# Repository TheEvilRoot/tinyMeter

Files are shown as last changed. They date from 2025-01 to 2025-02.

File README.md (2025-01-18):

# tinyMeter

Current/voltage meter board for 5V and 12V rails.

Provides:
- two USB-A outputs at 5V from single USB-C input 5V@3A max.
- one DC Jack output from DC jack output, 30V max.

Board is powered from separate USB-C with data lines connected MCU.

3V3 rail is powered by AMS1117-3.3 LDO regulator from master USB-C VBUS.

Has ESP32-S3 SoC as a MCU with in-package PSRAM and Flash. WiFi/Bluetooth antenna is implemented on PCB.

Power meter capability is done using INA219 chips from TI and 25mOhm shunts on power rails. Each rails can also be turned on/off by MCU using 100N03A N-channel MOSFETs on each rail.

Board supports ST7789 display connection using 0.7mm pitch FPC connector. 

Cuurrent PCB looks like:
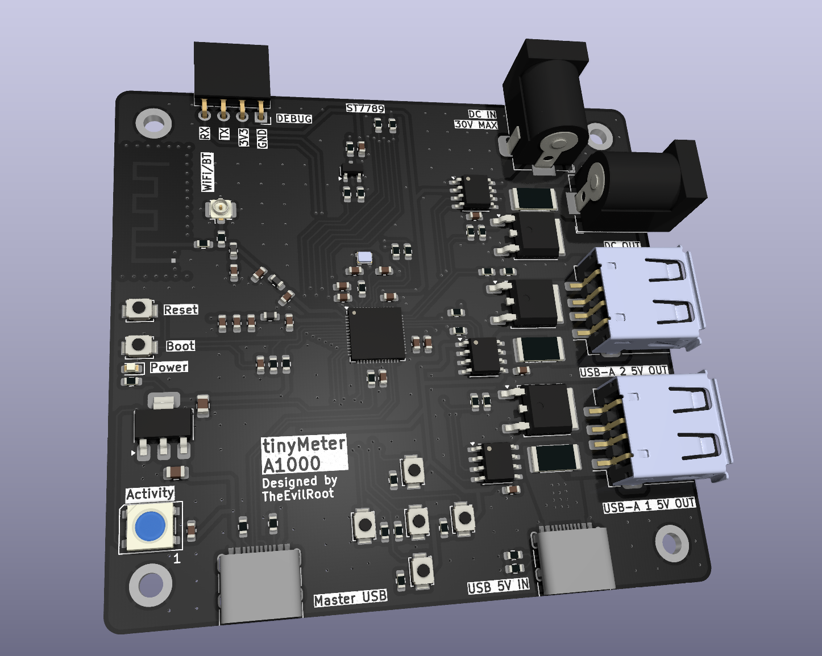
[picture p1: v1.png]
PCB


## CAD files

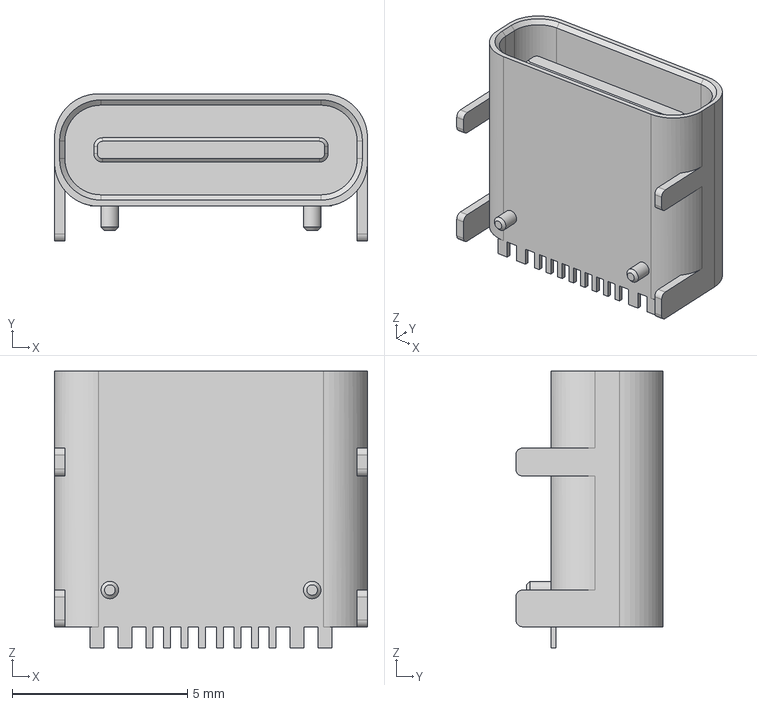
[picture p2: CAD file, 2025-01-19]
HRO TYPE-C-31-M-12.step
8.94 x 4.21 x 7.90 mm

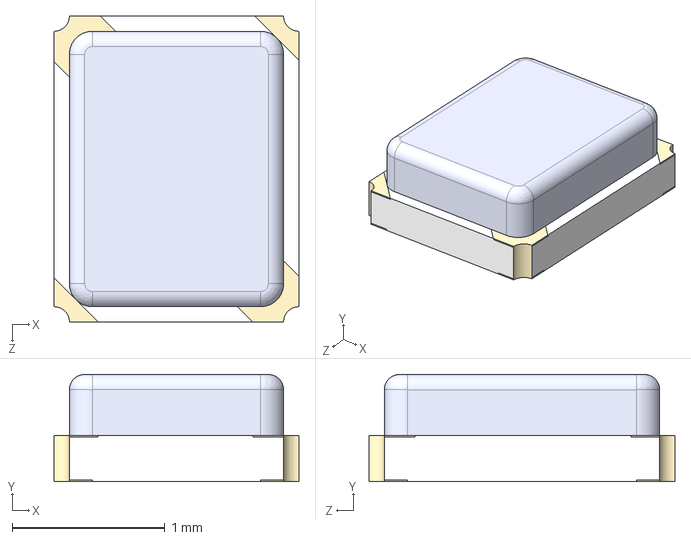
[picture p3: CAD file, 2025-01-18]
XRCGB40M000F4M00R0.step
1.60 x 0.7 x 2.00 mm

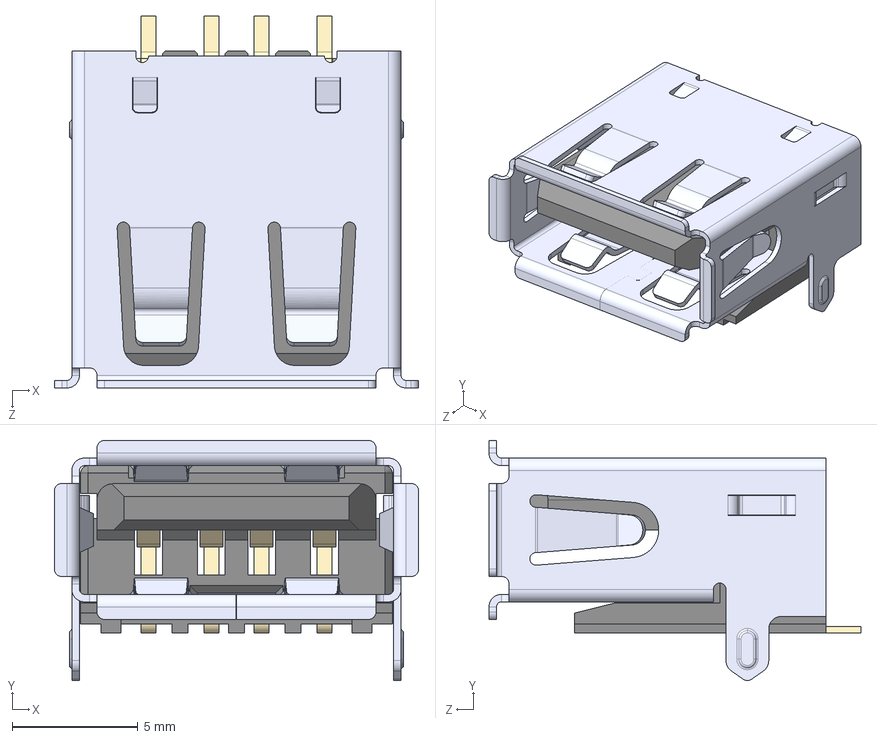
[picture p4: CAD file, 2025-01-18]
USB1046-XX-XXXX-X-B-X_REVB.step
14.5 x 9.55 x 14.8 mm

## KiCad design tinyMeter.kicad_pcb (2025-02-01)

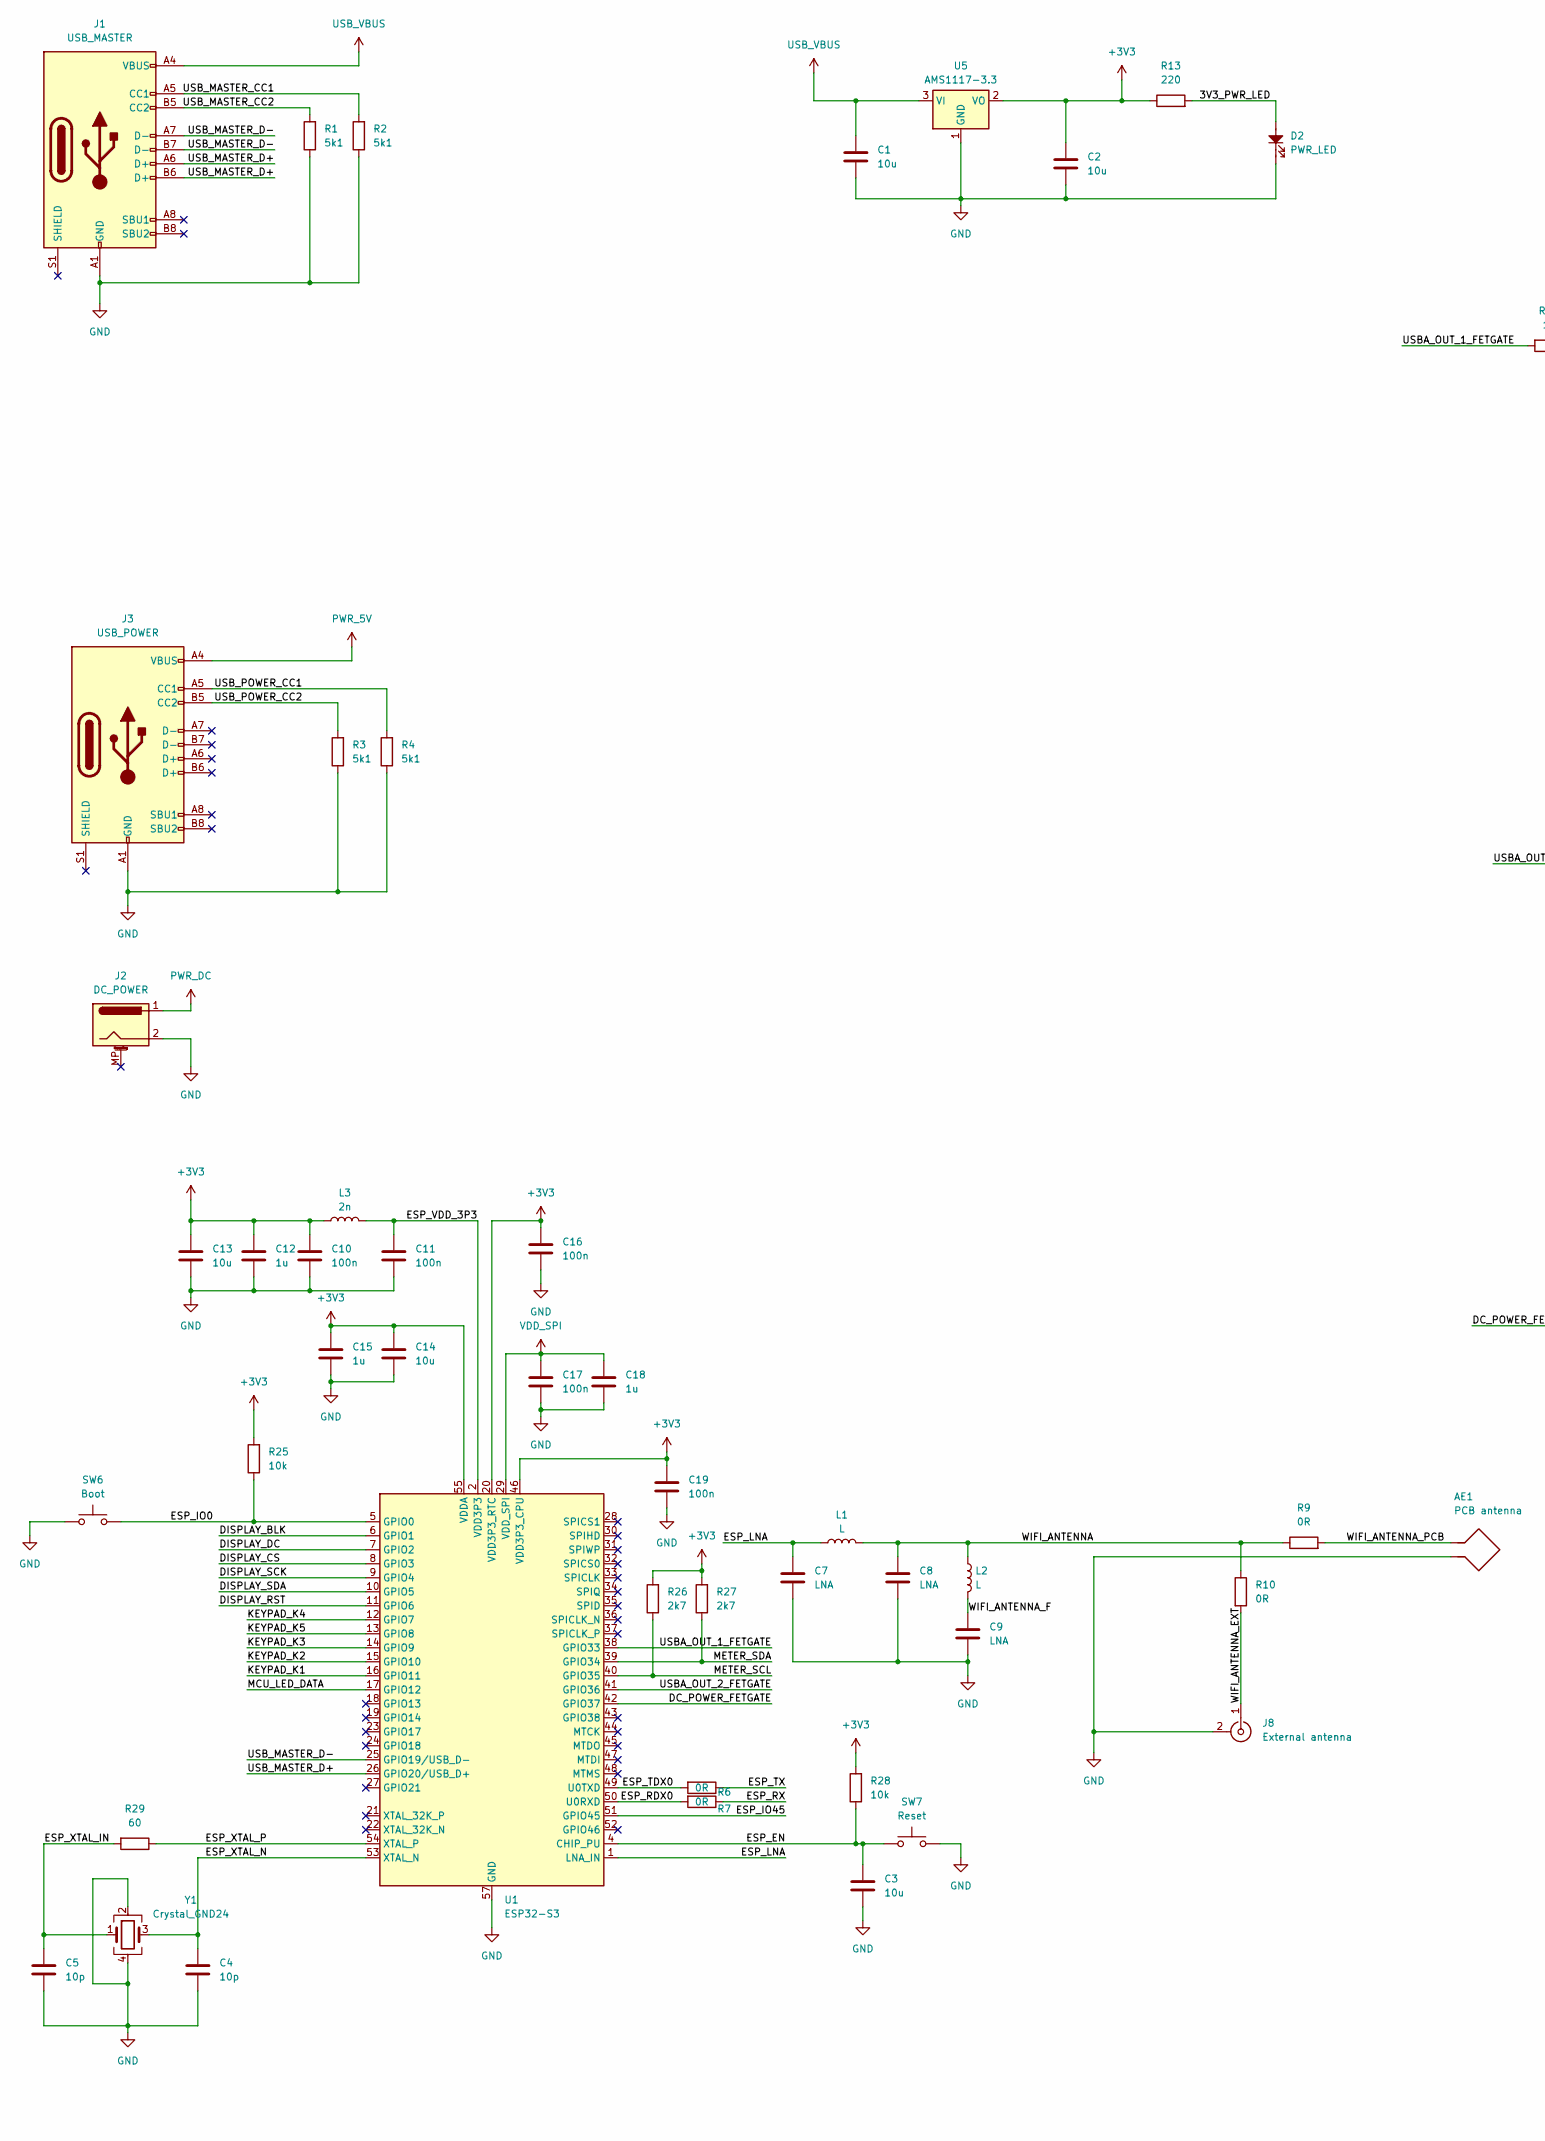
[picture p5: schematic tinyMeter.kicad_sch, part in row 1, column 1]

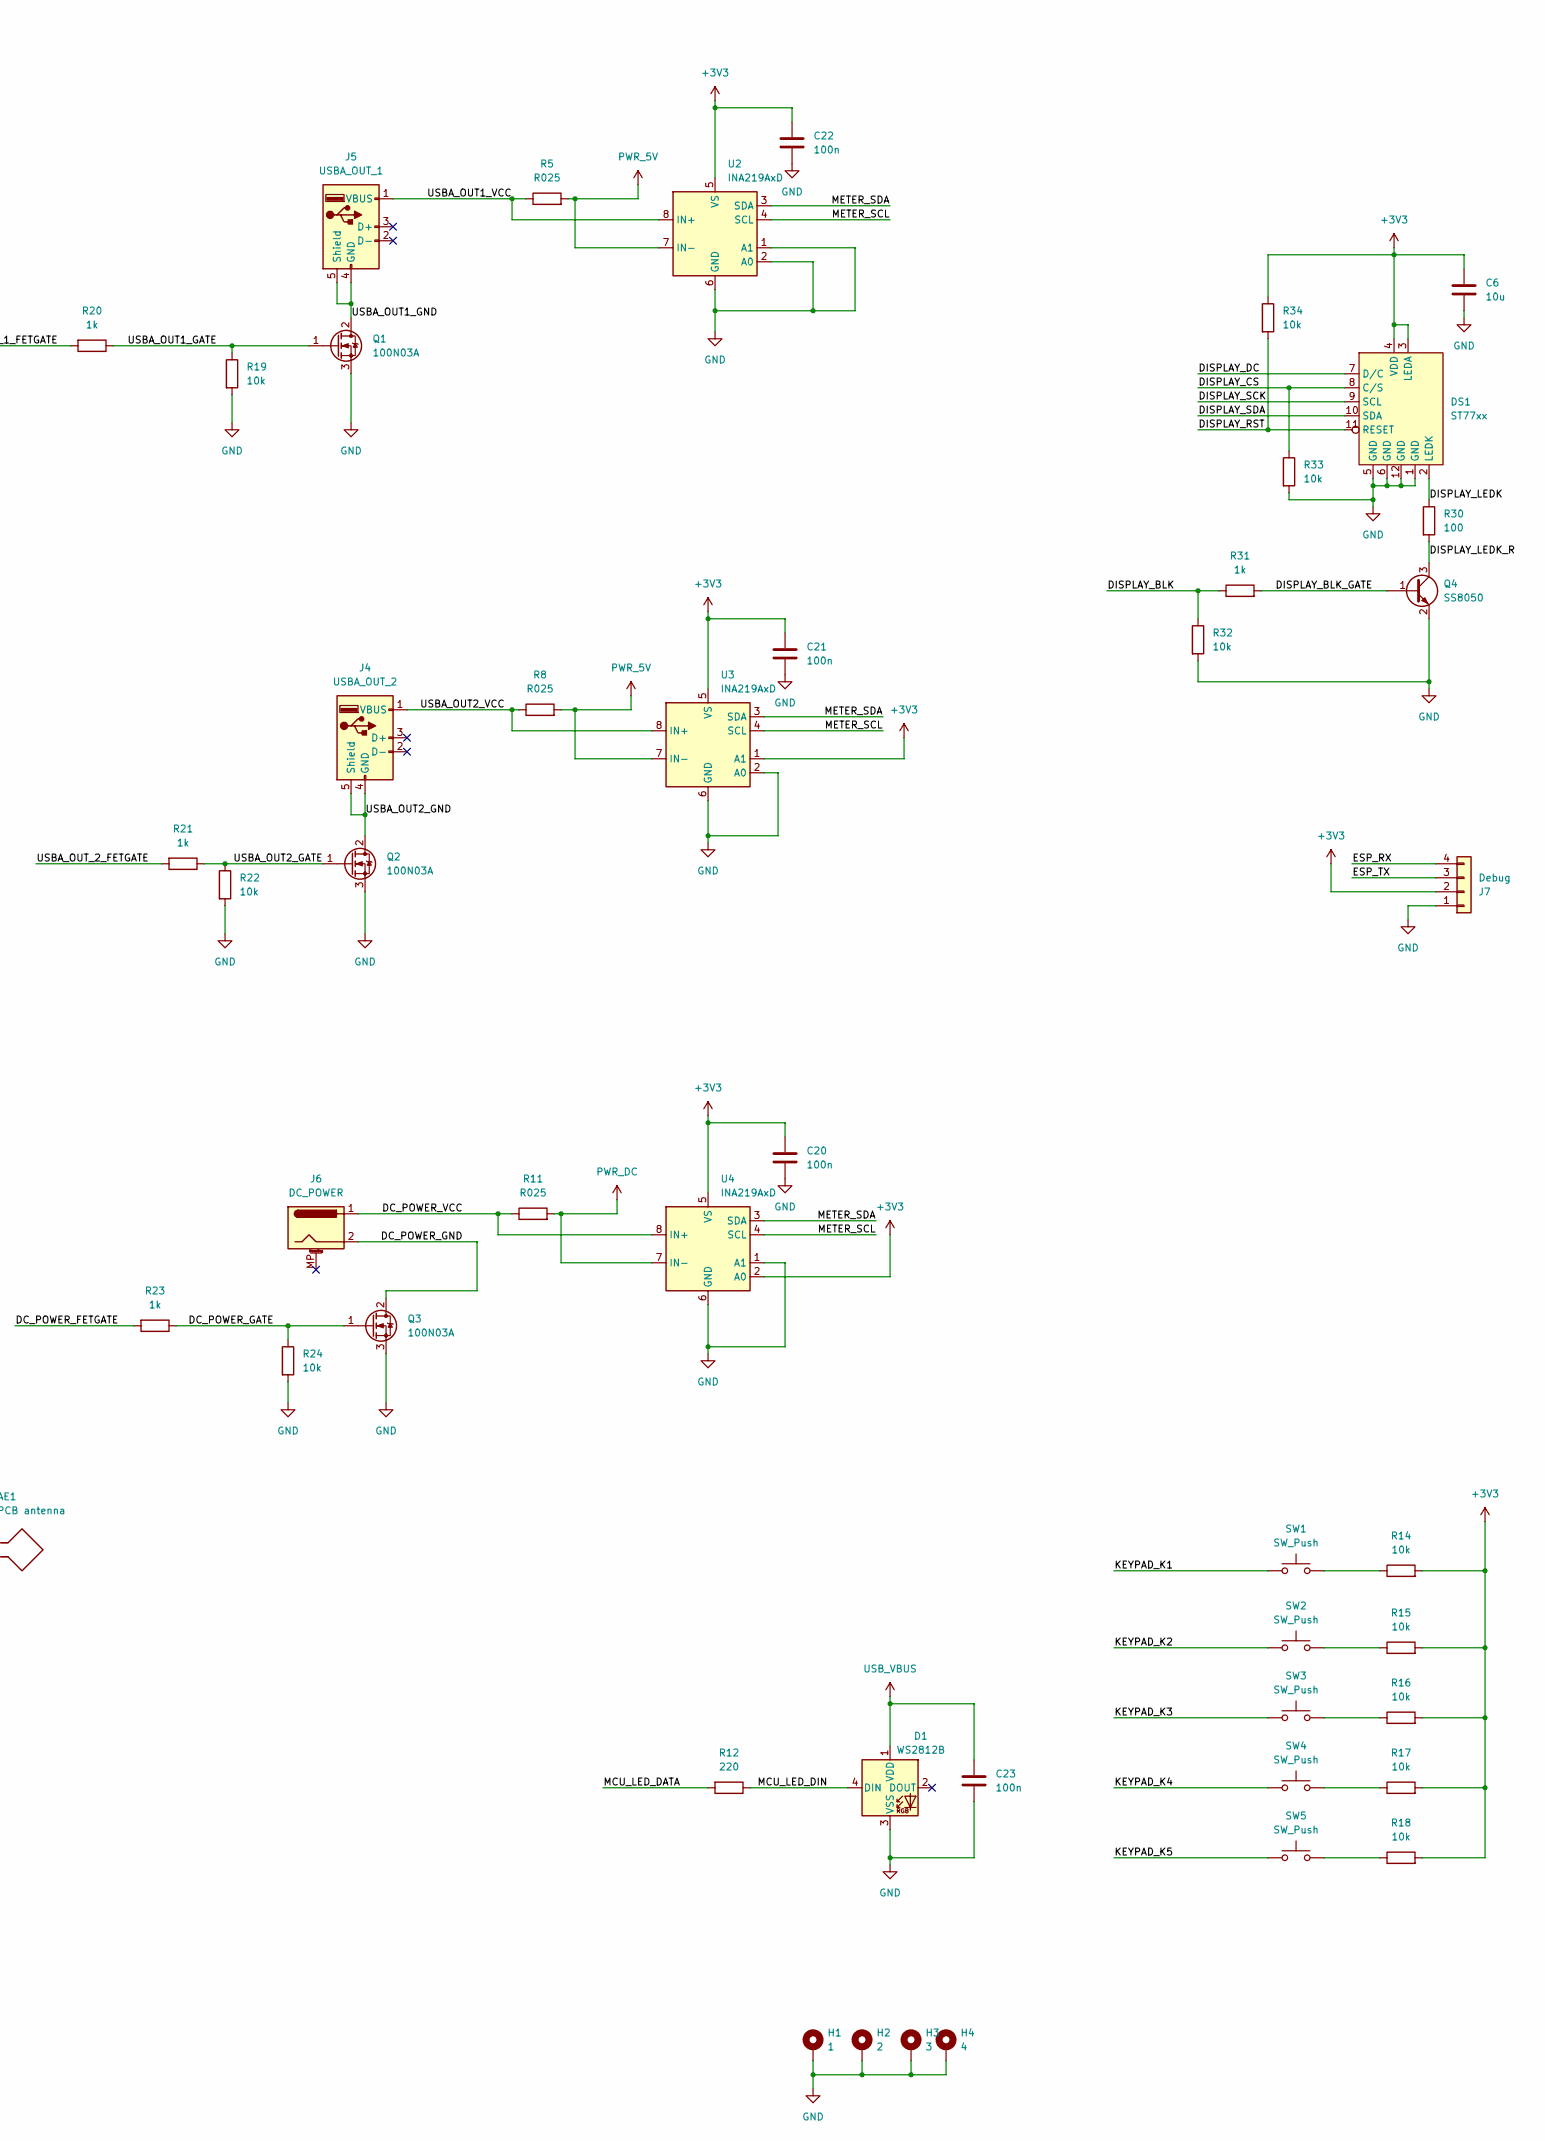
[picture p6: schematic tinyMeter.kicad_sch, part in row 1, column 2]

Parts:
AE1: PCB antenna; ESPRESSIF_ESP32_MIFA_2.4GHz_Right
C1, C2: 10u; C_0805_2012Metric
C3, C6, C13, C14: 10u; C_0603_1608Metric
C4, C5: 10p; C_0603_1608Metric
C7, C8, C9: LNA; C_0603_1608Metric
C10, C11, C16, C17, C19, C20, C21, C22, C23: 100n; C_0603_1608Metric
C12, C15, C18: 1u; C_0603_1608Metric
D1: WS2812B; LED_WS2812B_PLCC4_5.0x5.0mm_P3.2mm
D2: PWR_LED; LED_0603_1608Metric
DS1: ST77xx; ST77XX
H1: 1; MountingHole_2.7mm_M2.5_DIN965_Pad
H2: 2; MountingHole_2.7mm_M2.5_DIN965_Pad
H3: 3; MountingHole_2.7mm_M2.5_DIN965_Pad
H4: 4; MountingHole_2.7mm_M2.5_DIN965_Pad
J1: USB_MASTER; USB_C_Receptacle_HRO_TYPE-C-31-M-12
J2, J6: DC_POWER; BarrelJack_Horizontal
J3: USB_POWER; USB_C_Receptacle_HRO_TYPE-C-31-M-12
J4: USBA_OUT_2; USB_A_Receptacle_GCT_USB1046
J5: USBA_OUT_1; USB_A_Receptacle_GCT_USB1046
J7: Debug; PinSocket_1x04_P2.54mm_Horizontal
J8: External antenna; U.FL_Hirose_U.FL-R-SMT-1_Vertical
L1, L2: L; L_0603_1608Metric
L3: 2n; L_0603_1608Metric
Q1, Q2, Q3: 100N03A; TO-252-2
Q4: SS8050; SOT-23
R1, R2, R3, R4: 5k1; R_0603_1608Metric
R5, R8, R11: R025; R_2512_6332Metric
R6, R7, R9, R10: 0R; R_0603_1608Metric
R12, R13: 220; R_0603_1608Metric
R14, R15, R16, R17, R18, R19, R22, R24, R25, R28, R32, R33, R34: 10k; R_0603_1608Metric
R20, R21, R23, R31: 1k; R_0603_1608Metric
R26, R27: 2k7; R_0603_1608Metric
R29: 60; R_0603_1608Metric
R30: 100; R_0603_1608Metric
SW1, SW2, SW3, SW4, SW5: SW_Push; SW_SPST_B3U-1000P
SW6: Boot; SW_SPST_B3U-1000P
SW7: Reset; SW_SPST_B3U-1000P
U1: ESP32-S3; QFN-56-1EP_7x7mm_P0.4mm_EP4x4mm
U2, U3, U4: INA219AxD; SOIC-8_3.9x4.9mm_P1.27mm
U5: AMS1117-3.3; SOT-223-3_TabPin2
Y1: Crystal_GND24; OSC_XRCGB40M000F4M00R0

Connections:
+3V3: C2.1, C6.1, C10.1, C12.1, C13.1, C14.1, C15.1, C16.1, C19.1, C20.1, C21.1, C22.1, DS1.3 (LEDA), DS1.4 (VDD), J7.2, L3.1, R13.1, R14.2, R15.2, R16.2, R17.2, R18.2, R25.2, R26.2, R27.2, R28.2, R34.1, U1.20 (VDD3P3_RTC), U1.46 (VDD3P3_CPU), U1.55 (VDDA), U1.56 (VDDA), U2.5 (VS), U3.1 (A1), U3.5 (VS), U4.2 (A0), U4.5 (VS), U5.2 (VO)
/3V3_PWR_LED: D2.2, R13.2
/DC_POWER_FETGATE: R23.2, U1.42 (GPIO37)
/DC_POWER_GATE: Q3.1 (G), R23.1, R24.1
/DC_POWER_GND: J6.2, Q3.2 (D)
/DC_POWER_VCC: J6.1, R11.1, U4.8 (IN+)
/DISPLAY_BLK: R31.1, R32.1, U1.6 (GPIO1)
/DISPLAY_BLK_GATE: Q4.1 (B), R31.2
/DISPLAY_CS: DS1.8 (C/S), R33.1, U1.8 (GPIO3)
/DISPLAY_DC: DS1.7 (D/C), U1.7 (GPIO2)
/DISPLAY_LEDK: DS1.2 (LEDK), R30.1
/DISPLAY_LEDK_R: Q4.3 (C), R30.2
/DISPLAY_RST: DS1.11 (RESET), R34.2, U1.11 (GPIO6)
/DISPLAY_SCK: DS1.9 (SCL), U1.9 (GPIO4)
/DISPLAY_SDA: DS1.10 (SDA), U1.10 (GPIO5)
/ESP_EN: C3.1, R28.1, SW7.1, U1.4 (CHIP_PU)
/ESP_IO0: R25.1, SW6.2, U1.5 (GPIO0)
/ESP_IO45: U1.51 (GPIO45)
/ESP_LNA: C7.1, L1.1, U1.1 (LNA_IN)
/ESP_RDX0: R7.2, U1.50 (U0RXD)
/ESP_RX: J7.4, R7.1
/ESP_TDX0: R6.2, U1.49 (U0TXD)
/ESP_TX: J7.3, R6.1
/ESP_VDD_3P3: C11.1, L3.2, U1.2 (VDD3P3), U1.3 (VDD3P3)
/ESP_XTAL_IN: C5.1, R29.2, Y1.1
/ESP_XTAL_N: C4.1, U1.53 (XTAL_N), Y1.3
/ESP_XTAL_P: R29.1, U1.54 (XTAL_P)
/KEYPAD_K1: SW1.1, U1.16 (GPIO11)
/KEYPAD_K2: SW2.1, U1.15 (GPIO10)
/KEYPAD_K3: SW3.1, U1.14 (GPIO9)
/KEYPAD_K4: SW4.1, U1.12 (GPIO7)
/KEYPAD_K5: SW5.1, U1.13 (GPIO8)
/MCU_LED_DATA: R12.2, U1.17 (GPIO12)
/MCU_LED_DIN: D1.4 (DIN), R12.1
/METER_SCL: R26.1, U1.40 (GPIO35), U2.4 (SCL), U3.4 (SCL), U4.4 (SCL)
/METER_SDA: R27.1, U1.39 (GPIO34), U2.3 (SDA), U3.3 (SDA), U4.3 (SDA)
/USBA_OUT1_GATE: Q1.1 (G), R19.1, R20.1
/USBA_OUT1_GND: J5.4 (GND), J5.5 (Shield), Q1.2 (D)
/USBA_OUT1_VCC: J5.1 (VBUS), R5.1, U2.8 (IN+)
/USBA_OUT2_GATE: Q2.1 (G), R21.1, R22.1
/USBA_OUT2_GND: J4.4 (GND), J4.5 (Shield), Q2.2 (D)
/USBA_OUT2_VCC: J4.1 (VBUS), R8.1, U3.8 (IN+)
/USBA_OUT_1_FETGATE: R20.2, U1.38 (GPIO33)
/USBA_OUT_2_FETGATE: R21.2, U1.41 (GPIO36)
/USB_MASTER_CC1: J1.A5 (CC1), R2.2
/USB_MASTER_CC2: J1.B5 (CC2), R1.2
/USB_MASTER_D+: J1.A6 (D+), J1.B6 (D+), U1.26 (GPIO20/USB_D+)
/USB_MASTER_D-: J1.A7 (D-), J1.B7 (D-), U1.25 (GPIO19/USB_D-)
/USB_POWER_CC1: J3.A5 (CC1), R4.2
/USB_POWER_CC2: J3.B5 (CC2), R3.2
/WIFI_ANTENNA: C8.1, L1.2, L2.1, R9.1, R10.1
/WIFI_ANTENNA_EXT: J8.1 (In), R10.2
/WIFI_ANTENNA_F: C9.1, L2.2
/WIFI_ANTENNA_PCB: AE1.1, R9.2
GND: AE1.2, C1.2, C2.2, C3.2, C4.2, C5.2, C6.2, C7.2, C8.2, C9.2, C10.2, C11.2, C12.2, C13.2, C14.2, C15.2, C16.2, C17.2, C18.2, C19.2, C20.2, C21.2, C22.2, C23.2, D1.3 (VSS), D2.1, DS1.1 (GND), DS1.5 (GND), DS1.6 (GND), DS1.12 (GND), H1.1, H2.1, H3.1, H4.1, J1.A1 (GND), J1.A12 (GND), J1.B1 (GND), J1.B12 (GND), J2.2, J3.A1 (GND), J3.A12 (GND), J3.B1 (GND), J3.B12 (GND), J7.1, J8.2 (Ext), Q1.3 (S), Q2.3 (S), Q3.3 (S), Q4.2 (E), R1.1, R2.1, R3.1, R4.1, R19.2, R22.2, R24.2, R32.2, R33.2, SW6.1, SW7.2, U1.57 (GND), U2.1 (A1), U2.2 (A0), U2.6 (GND), U3.2 (A0), U3.6 (GND), U4.1 (A1), U4.6 (GND), U5.1 (GND), Y1.2, Y1.4
unnamed: R14.1, SW1.2
unnamed: R15.1, SW2.2
unnamed: R16.1, SW3.2
unnamed: R17.1, SW4.2
unnamed: R18.1, SW5.2
PWR_5V: J3.A4 (VBUS), J3.A9 (VBUS), J3.B4 (VBUS), J3.B9 (VBUS), R5.2, R8.2, U2.7 (IN-), U3.7 (IN-)
PWR_DC: J2.1, R11.2, U4.7 (IN-)
USB_VBUS: C1.1, C23.1, D1.1 (VDD), J1.A4 (VBUS), J1.A9 (VBUS), J1.B4 (VBUS), J1.B9 (VBUS), U5.3 (VI)
VDD_SPI: C17.1, C18.1, U1.29 (VDD_SPI)

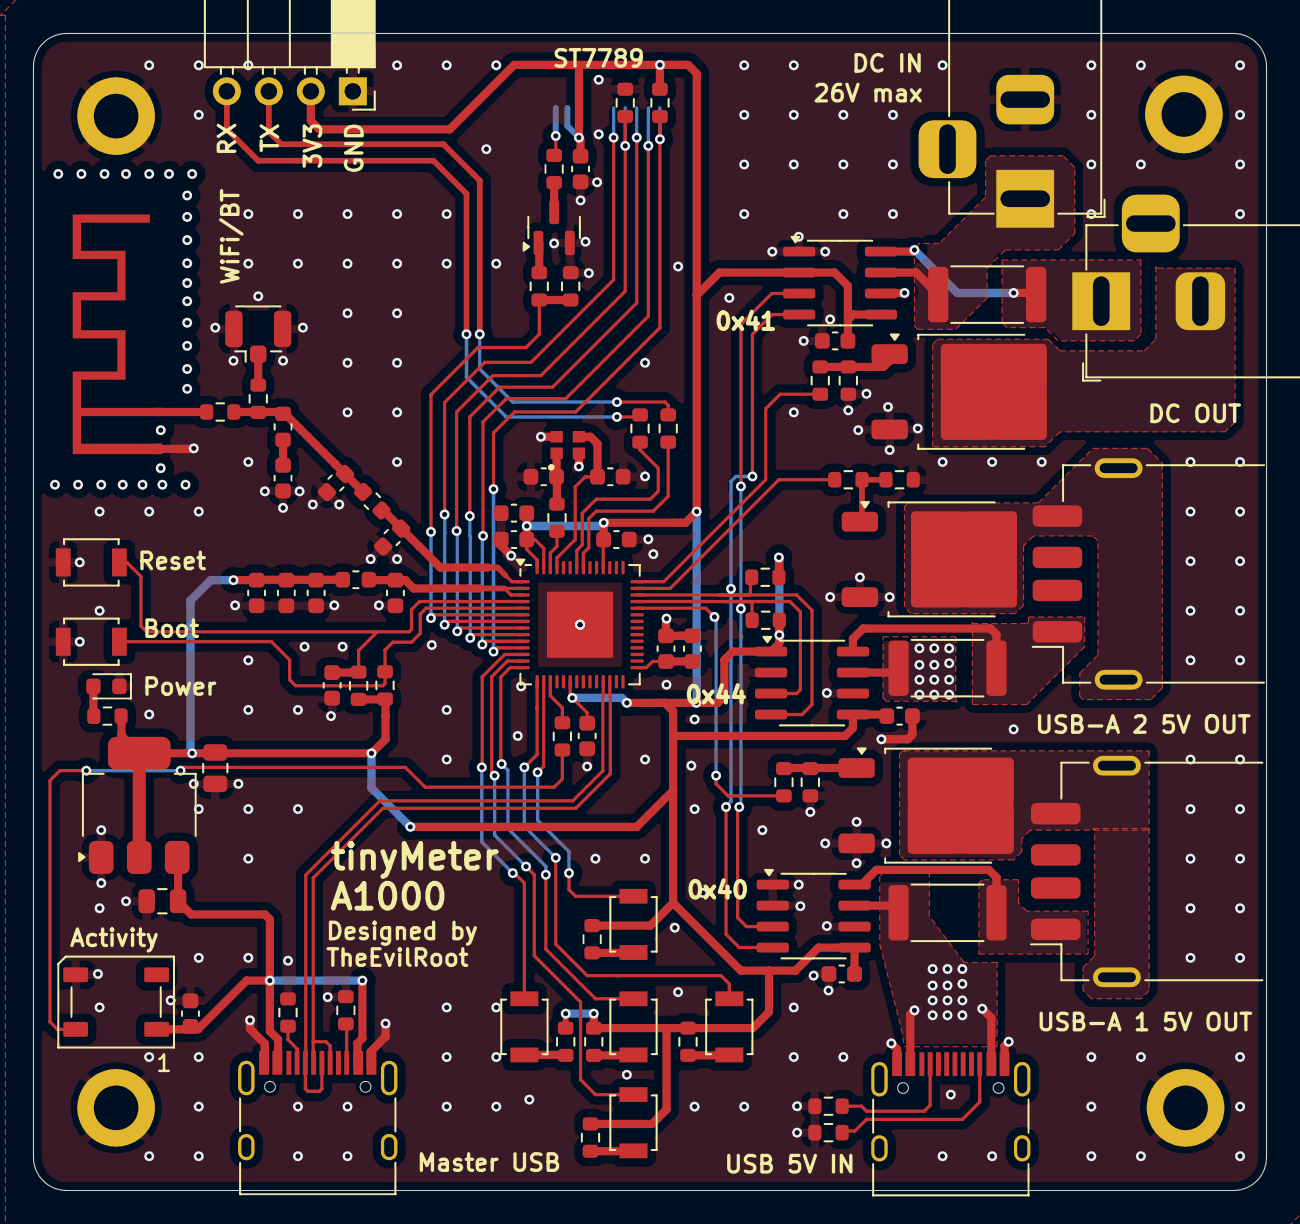
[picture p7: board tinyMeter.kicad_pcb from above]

Board: 2 copper layers, 74.6 x 70.0 mm, 93 parts (1 on the bottom side), 63 nets.

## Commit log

2025-01-17 v1 start
    [tinyMeter.kicad_pcb, tinyMeter.kicad_sch]
2025-01-17 Rough schematic and start of layout
    [tinyMeter.kicad_pcb, tinyMeter.kicad_sch]
2025-01-18 Rough layout and routing
    [USB1046-XX-XXXX-X-B-X_REVB.step, tinyMeter.kicad_pcb, tinyMeter.kicad_sch]
2025-01-18 More layout
    - Some traces refactor
    - Add debug connector with UART lines
    - Add external WiFi/BT connector and selector for PCB/Ext
    - Add WS8212B LED just for fun
    - Add power indication LED on 3V3
    - Remove RefDes silkscreen; add useful silkscreen
    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
    [XRCGB40M000F4M00R0.step, tinyMeter.kicad_pcb, tinyMeter.kicad_sch]
2025-01-19 Fixes and schematic refactor
    - Refactor schematic to get more space
    - Assign nets where missing
    - Change footprint of USB-C
    - Add 3D model for USB-C footprint
    - Changes to board setup
    [HRO TYPE-C-31-M-12.step, tinyMeter.kicad_pcb, tinyMeter.kicad_sch]
2025-01-19 Some rerouting. Via stitching. Align mouting holes
    [tinyMeter.kicad_pcb]
2025-01-22 Fix display connector orientation
    [tinyMeter.kicad_pcb, tinyMeter.kicad_sch]
2025-01-22 Remove most of knockouts from silkscreen
    [tinyMeter.kicad_pcb]
2025-01-22 Tiny rerouting
    [tinyMeter.kicad_pcb]
2025-02-01 Fix DC voltage rating
    [tinyMeter.kicad_pcb]
